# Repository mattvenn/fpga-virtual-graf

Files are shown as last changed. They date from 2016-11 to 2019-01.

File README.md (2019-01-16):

# FPGA Virtual Graffiti

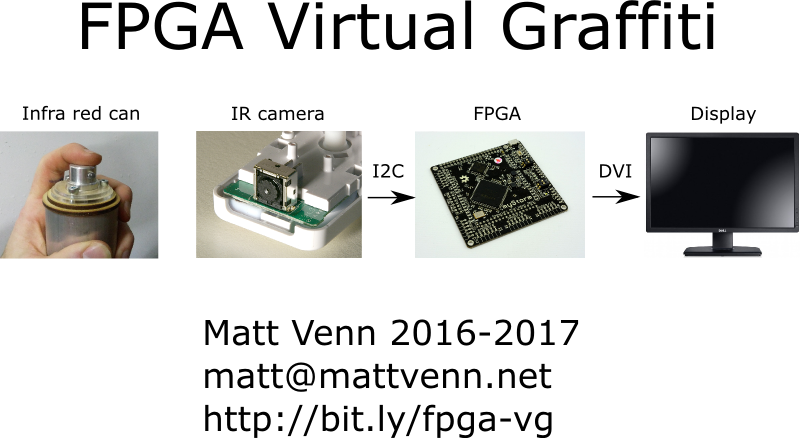
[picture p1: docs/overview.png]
overview


[videos and construction photos](https://photos.app.goo.gl/kivlfcmlp4oecVpu1)

# Tools used

* [icestorm](http://www.clifford.at/icestorm/) opensource FPGA tools.
* [mystorm](https://mystorm.uk/) open hardware FPGA development board
* [gtkwave](http://gtkwave.sourceforge.net/) for debugging.

# Top resource tips

* [Obijuan's FPGA tutorial](https://github.com/Obijuan/open-fpga-verilog-tutorial/wiki)
* [FPGAwars forum](https://groups.google.com/forum/#!forum/fpga-wars-explorando-el-lado-libre)
* [Dan's FPGA blog](http://www.zipcpu.com/)

# Documentation

* [system overview diagram](docs/module_overview.svg)
* Yosys can generate output graphs of the verilog with the [show](http://www.clifford.at/yosys/cmd_show.html) command.
* [schematic for mystorm](https://gitlab.com/Folknology/mystorm/blob/BlackIce/BlackIce-schematic.pdf)
* [ICEfloorplan](https://knielsen.github.io/ice40_viewer/ice40_viewer.html) can be used to show how the design is laid out on the FPGA
* [All Verilog source](src) and [tests](tests)

# Build notes

## Synthesis

    make

To program the mystorm board, first start a terminal listening on /dev/ttyUSBX
at 115200 baud, and reset the board. Then type:

    make prog

## Tests

many test benches are in [tests](tests). They can be simulated and outputs
viewed with gtkwave:

    make debug-[name of verilog file]

eg

    make debug-bresenham
    
## Storing configuration on the board

[Instructions
here](https://forum.mystorm.uk/t/config-from-non-voltatile-memory/242/2)

## SRAM video buffer

Using the SRAM on the back of the board for persistant graffitis. This caused 2
major issues:

* [PLL and SRAM pins collide on the board layout](https://forum.mystorm.uk/t/placement-conflict-between-sb-io-for-ram-and-pll/224/12)
* [switching the SB_IO pins and SRAM pins at the same time](https://forum.mystorm.uk/t/fpga-unreliability-crashing-hanging/252/19) caused instability.

## Wiimote Camera

* (breakout board)[https://github.com/mattvenn/kicad/tree/master/wiimote-fpga)
* 25mhz supplied on clock pin
* reset high to run
* wiimote camera PCB was tested with branch wii-pcb

## I2C reader / writer

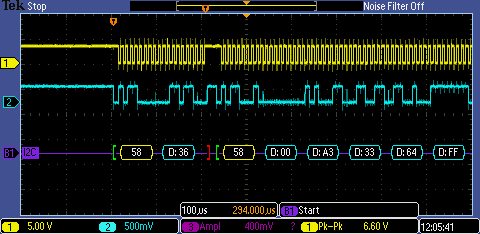
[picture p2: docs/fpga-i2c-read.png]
fpga read


Started off with this youtube series:https://www.youtube.com/watch?v=rWzB5hZlqBA
by Tom Briggs.

In Tom's design, the I2C clock is assigned to the state machine's !clk.

Writing and requesting data was easy, but reading the data was difficult to
synchronize the clock. I then tried 2 different approaches:

* separating the I2C clock and state machine clock to give more time for reading
 data (4 state machine clocks for 1 I2C clock)
* generating the clock within the state machine itself.

Option 2 proved much easier to write. I also found this [brief Q&A on reddit on
the same topic](https://m.reddit.com/r/FPGA/comments/4oltue/when_writing_communication_protocols_spi_i2c_etc/)

## DVI output

based on [Hamster's minimal DVI-D
VHDL](http://hamsterworks.co.nz/mediawiki/index.php/Minimal_DVI-D)

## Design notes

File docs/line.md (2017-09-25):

# Line drawing algorithm resources

* https://github.com/kavinr/Bresenham-Line-Drawing-Algorithm
* https://en.wikipedia.org/wiki/Bresenham%27s_line_algorithm
* https://www.youtube.com/watch?v=IDFB5CDpLDE
* http://www.cs.columbia.edu/~sedwards/classes/2015/4840/lines.pdf

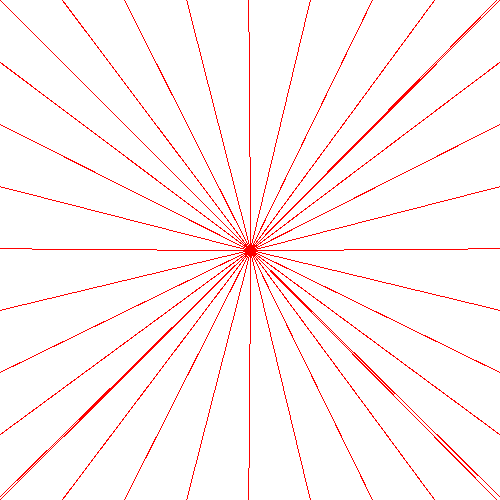
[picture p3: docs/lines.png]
lines


Drawn using Bresenham's algorithm, adapted for integer maths: [line.py](line.py)

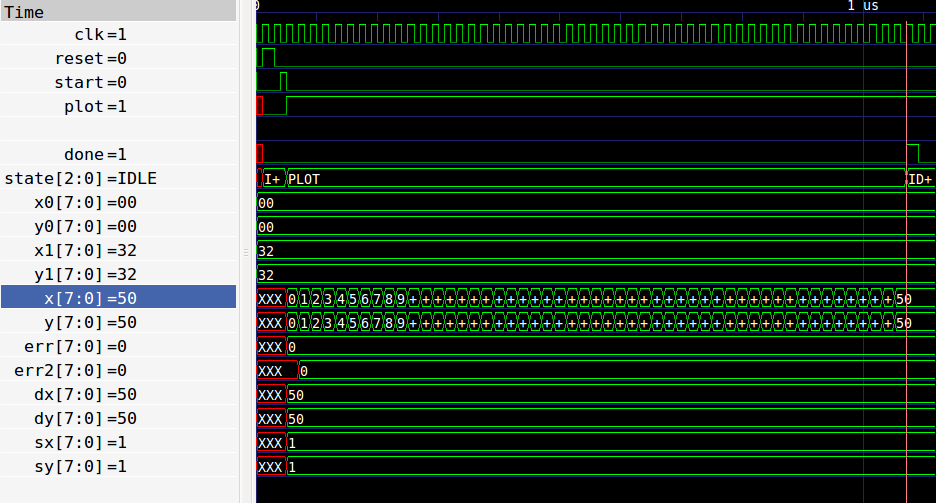
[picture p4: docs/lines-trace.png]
line strace


Shows simulation of algorithm using [bresenham.v](../bresenham.v).

After initial calculation, each pixel takes one clock cycle to draw. SRAM takes
about 10 clocks for a read then write for each pixel location.

At 640 x 480, there is a region at the bottom of the screen where the SRAM is
not being used. 45 blank lines @ 800 pix wide = 36k clocks.

So 36k / 15 clocks per pixel of a line = 2400 pixels maximum line length before
beginning to draw the screen again. Diagonal of the screen is 800px, so there is
time to draw the longest line possible.

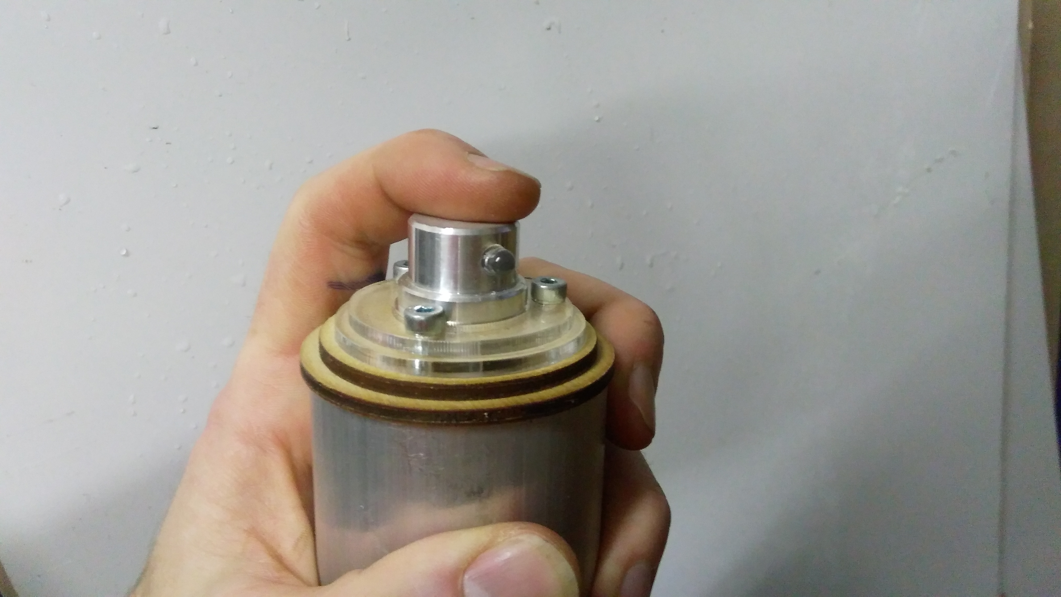
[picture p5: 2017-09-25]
docs/can.jpg

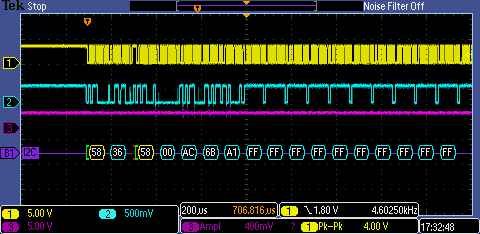
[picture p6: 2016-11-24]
docs/arduino-fullframe.png

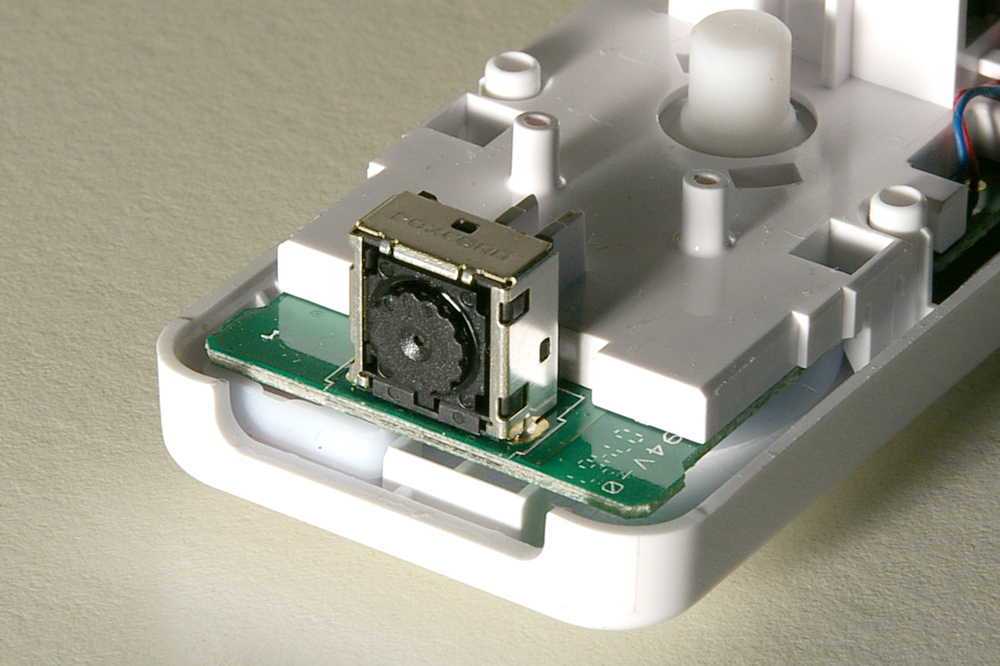
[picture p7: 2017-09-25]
docs/wii_sensor_03.jpg

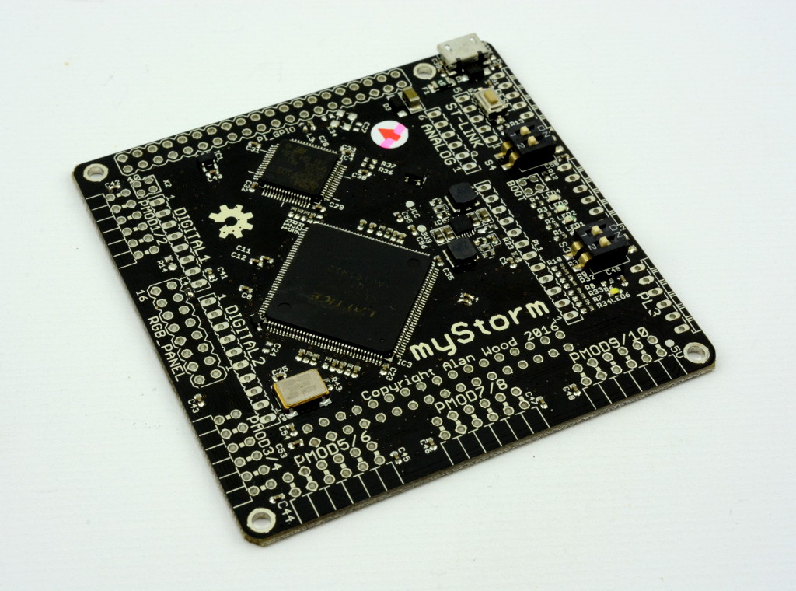
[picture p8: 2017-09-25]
docs/myStorm_1024w.jpg

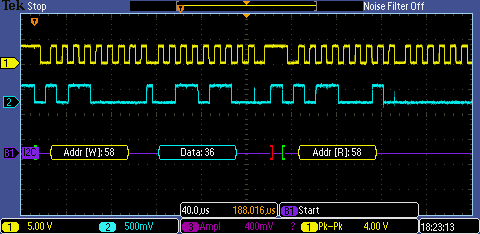
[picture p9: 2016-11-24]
docs/arduino-start.png

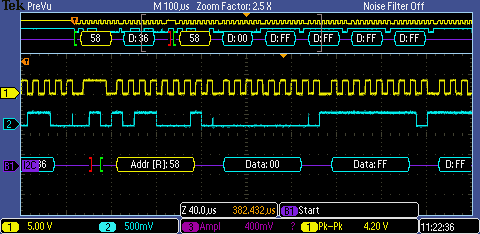
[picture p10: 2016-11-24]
docs/arduino-readbyte.png

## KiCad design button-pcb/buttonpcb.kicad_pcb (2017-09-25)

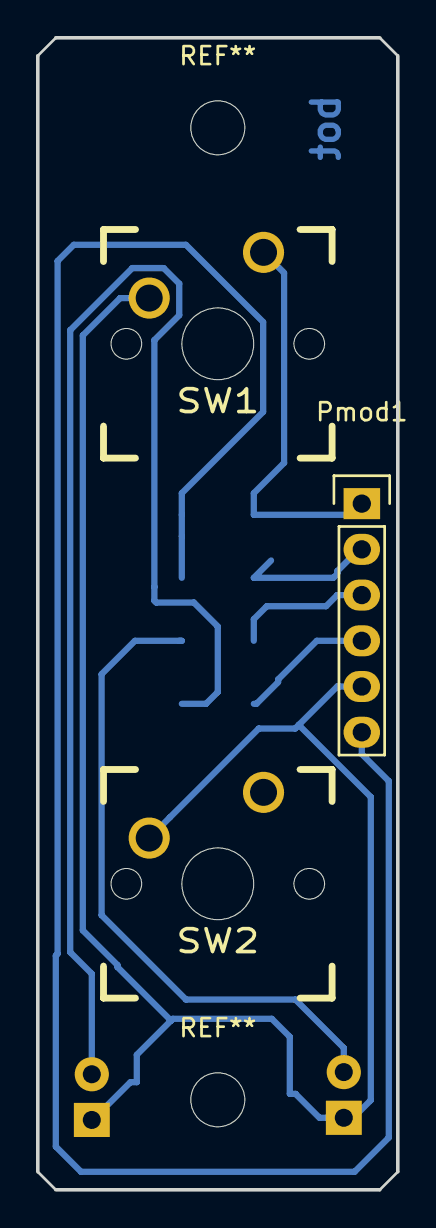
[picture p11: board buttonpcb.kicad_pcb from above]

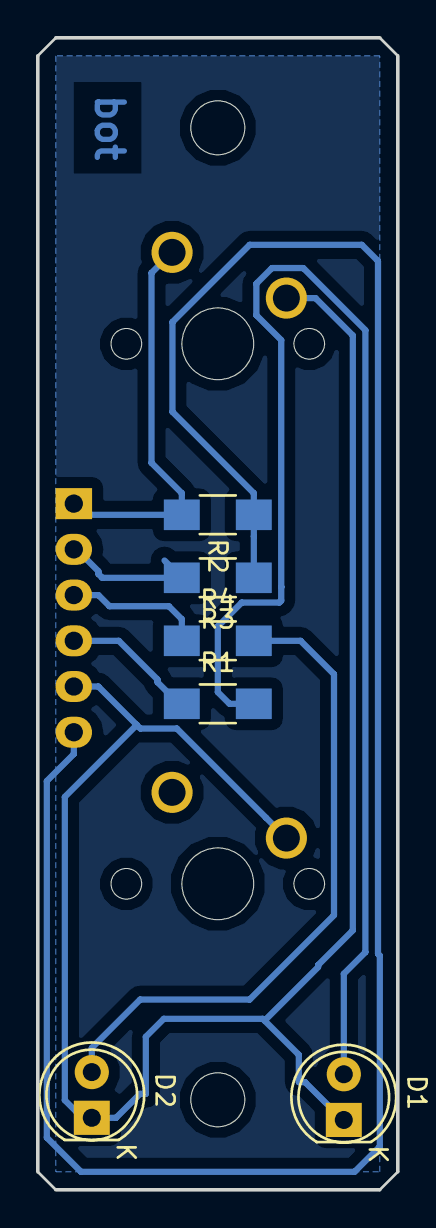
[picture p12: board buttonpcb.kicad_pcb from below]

Board: 2 copper layers, 20.0 x 64.0 mm, 9 parts (6 on the bottom side), 8 nets.

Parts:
D1, D2: LED; LED-5MM
Pmod1: CONN_01X06; Pin_Header_Straight_1x06
R1, R2, R3, R4: R; R_1206_HandSoldering
SW1, SW2: SW_PUSH; CHERRY_MX

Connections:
/b1: Pmod1.2, R3.2, SW2.1
/b2: Pmod1.1, R2.2, SW1.1
/led: Pmod1.4, R1.1
/led2: Pmod1.3, R4.1
Earth: D1.1, D2.1, Pmod1.5, SW1.2, SW2.2
unnamed: D1.2, R1.2
unnamed: D2.2, R4.2
VCC: Pmod1.6, R2.1, R3.1

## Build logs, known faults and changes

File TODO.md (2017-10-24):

# Todo

* default cases for state machines
* docs
    * svg overview - done
    * floorplan - done
    * simple module, verilog and svg (pulse.v) - done
    * medium module, verilog and svg (vga.v) - done
    * complex module, verilog and svg (bresenham.v) - done
    * coverpage - done
    * some kind of hand out with all the links - print a few README.md
    * output of yosys netlist?
    * lut definition of lattice - done
    * gtkwave signals
* recut case

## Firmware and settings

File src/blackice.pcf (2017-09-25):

################################################################################
##                                                                             #
## Copyright 2016 myStorm Copyright and related                                #
## rights are licensed under the Solderpad Hardware License, Version 0.51      #
## (the “License”); you may not use this file except in compliance with        #
## the License. You may obtain a copy of the License at                        #
## http://solderpad.org/licenses/SHL-0.51. Unless required by applicable       #
## law or agreed to in writing, software, hardware and materials               #
## distributed under this License is distributed on an “AS IS” BASIS,          #
## WITHOUT WARRANTIES OR CONDITIONS OF ANY KIND, either express or             #
## implied. See the License for the specific language governing                #
## permissions and limitations under the License.                              #
##                                                                             #
################################################################################
#
## User Constraint File for myStorm
#
##pmod 1 lvds pairs 2 & 5
#
set_io --warn-no-port PMOD[0] 94 # rd6
set_io --warn-no-port PMOD[1] 91 # rd4
set_io --warn-no-port PMOD[2] 88 # rd2
set_io --warn-no-port PMOD[3] 85 # rd0

#pmod 2 lvds pairs 3 & 4
set_io --warn-no-port PMOD[4] 95 # rd7
set_io --warn-no-port PMOD[5] 93 # rd5
set_io --warn-no-port PMOD[6] 90 # rd3
set_io --warn-no-port PMOD[7] 87 # rd1

#pmod 3 GPIO
#set_io --warn-no-port PMOD[8] 105 # c5
#set_io --warn-no-port PMOD[9] 102 # c3
#set_io --warn-no-port PMOD[10] 99 # c1
#set_io --warn-no-port PMOD[11] 97 # i_tx


set_io --warn-no-port i2c_sda 105
set_io --warn-no-port i2c_scl 102
set_io --warn-no-port pixartclk 99
set_io --warn-no-port pixart_reset 97
#set_io --warn-no-port i2c_sda_dir 104
#set_io pixartclk 62
#set_io button 44

#pmod 4
set_io --warn-no-port reset_button 104 # c4
set_io --warn-no-port erase_button 101 # c2
set_io --warn-no-port status_led 98 # c0
set_io --warn-no-port cam_led 96 # i_rx
#
##pmod 5 GPIO (top level of pins)
set_io --warn-no-port PMOD[16] 143 #g2
set_io --warn-no-port PMOD[17] 114 #c11
set_io --warn-no-port PMOD[18] 112 #c9
set_io --warn-no-port PMOD[19] 107 #c7
#
##pmod 6 GPIO
set_io --warn-no-port PMOD[20] 144 #G1
set_io --warn-no-port PMOD[21] 113 #C10
set_io --warn-no-port PMOD[22] 110 #C8
set_io --warn-no-port PMOD[23] 106 #C6
#
##pmod 7 
set_io --warn-no-port PMOD[24] 10 # 5b
set_io --warn-no-port PMOD[25] 9 # 5a
set_io --warn-no-port PMOD[26] 2 # 2b
set_io --warn-no-port PMOD[27] 1 # 2a
#
##pmod 8 
set_io --warn-no-port PMOD[28] 8 # 4b
set_io --warn-no-port PMOD[29] 7 # 4a
set_io --warn-no-port PMOD[30] 4 # 3b
set_io --warn-no-port PMOD[31] 3 # 3a
#
##pmod 9 lvds pairs 10 & 13
#set_io --warn-no-port PMOD[32] 20 # 13b
#set_io --warn-no-port PMOD[33] 19 # 13a
#set_io --warn-no-port PMOD[34] 16 # 10b
#set_io --warn-no-port PMOD[35] 15 # 10a
#
##pmod 10 lvds pairs 8 & 12
#set_io --warn-no-port PMOD[36] 18 # 12b
#set_io --warn-no-port PMOD[37] 17 # 12a
#set_io --warn-no-port PMOD[38] 12 # 8b
#set_io --warn-no-port PMOD[39] 11 # 8a
#
##pmod 11 lvds pairs 14 & 25
#set_io --warn-no-port PMOD[40] 34 # 25b
#set_io --warn-no-port PMOD[41] 33 # 25a
#set_io --warn-no-port PMOD[42] 22 # 14B
#set_io --warn-no-port PMOD[43] 21 # 14a
#
##pmod 12 lvds pairs 18 & 24
#set_io --warn-no-port PMOD[44] 32 # 24b
#set_io --warn-no-port PMOD[45] 31 # 24a
#set_io --warn-no-port PMOD[46] 26 # 18b
#set_io --warn-no-port PMOD[47] 25 # 18a
#
##pmod 13 lvds pairs 17 & 23
#set_io --warn-no-port PMOD[48] 29 # 23b
#set_io --warn-no-port PMOD[49] 28 # 23a
#set_io --warn-no-port PMOD[50] 24 # 17b
#set_io --warn-no-port PMOD[51] 23 # 17a
#

set_io --warn-no-port BUTTON[0] 63
set_io --warn-no-port BUTTON[1] 64

#
# SRAM
set_io --warn-no-port ADR[0] 137
set_io --warn-no-port ADR[1] 138
set_io --warn-no-port ADR[2] 139
set_io --warn-no-port ADR[3] 141
set_io --warn-no-port ADR[4] 142
set_io --warn-no-port ADR[5] 42
set_io --warn-no-port ADR[6] 43
set_io --warn-no-port ADR[7] 44
set_io --warn-no-port ADR[8] 73
set_io --warn-no-port ADR[9] 74
set_io --warn-no-port ADR[10] 75
set_io --warn-no-port ADR[11] 76
set_io --warn-no-port ADR[12] 115
set_io --warn-no-port ADR[13] 116
set_io --warn-no-port ADR[14] 117
set_io --warn-no-port ADR[15] 118
set_io --warn-no-port ADR[16] 119
set_io --warn-no-port ADR[17] 78
#set_io --warn-no-port ADR[18] 62
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

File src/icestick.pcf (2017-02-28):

set_io LED1 99 # right
set_io LED2 98 # bot
set_io LED3 97 # left
set_io LED4 96 # top
set_io LED5 95 # centre green
set_io clk 21

set_io pixartclk 62
set_io i2c_scl 61
set_io i2c_sda 60
set_io i2c_sda_in 56
set_io button 44

#set_io cam_reset 48
#set_io clk_out 48

# J1
set_io PIO0[0] 112 # Pin 3
set_io PIO0[1] 113 # Pin 4
set_io PIO0[2] 114 # Pin 5
set_io PIO0[3] 115 # Pin 6
set_io PIO0[4] 116 # Pin 7
set_io PIO0[5] 117 # Pin 8
set_io PIO0[6] 118 # Pin 9
set_io PIO0[7] 119 # Pin 10 MSB

# Connector J3
#set_io PIO2_17 62 # Pin 3
#set_io PIO2_16 61 # Pin 4
#set_io PIO2_15 60 # Pin 5
#set_io PIO2_14 56 # Pin 6
#set_io PIO2_13 48 # Pin 7
#set_io PIO2_12 47 # Pin 8
#set_io PIO2_11 45 # Pin 9
#set_io PIO2_10 44 # Pin 10

set_io --warn-no-port PMOD[0] 78
set_io --warn-no-port PMOD[1] 79
set_io --warn-no-port PMOD[2] 80
set_io --warn-no-port PMOD[3] 81
set_io --warn-no-port PMOD[4] 87
set_io --warn-no-port PMOD[5] 88
set_io --warn-no-port PMOD[6] 90
set_io --warn-no-port PMOD[7] 91

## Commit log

2016-10-27 i2c state machine
2016-10-28 valid i2c
2016-10-28 sending single packet on button press
2016-11-03 button works, and faster i2c clock
2016-11-07 button pulse & test
2016-11-24 camera i2c reads working
2016-11-25 leds to show where sensor detects ir led
2016-12-06 i2c read fail docs
2016-12-07 fixed reading from i2c_sda_tri bug
    [camera.v, icestick.pcf]
2016-12-07 fixed tristate issue with 2 pins
    [camera.v, icestick.pcf]
2016-12-08 showing i2c bytes on debug byte
2016-12-26 data rx seems to be working, sums are broken
    [camera.v]
2016-12-28 fixed broken camera maths, only show leds if data is valid
    [camera.v]
2017-05-07 partially working with blackice board - hangs after some seconds
2017-08-28 traced pll issue and now builds but without full sram bus
    [blackice.pcf]
2017-09-03 output counter onto video, only increment when button is not pressed
2017-09-03 added camera
2017-09-04 can control blocks of 16 pixels with camera
2017-09-11 explicit control of inout pin direction
2017-09-12 added camera write
2017-09-16 map camera output range to screen size
2017-09-19 added button board
2017-09-20 clock enabled camera modules
2017-09-21 switched to array for more efficient synthesis
2017-09-22 removed button
2017-09-22 renamed i2c to top, changed project name to vgraf
2017-10-11 fixed camera bug by delaying start of i2c comms
    [camera.v]
2017-10-11 removed i2c debugging
2017-10-22 show wire or reg by closed or open box
